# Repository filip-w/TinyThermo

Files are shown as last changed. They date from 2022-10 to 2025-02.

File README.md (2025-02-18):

# TinyThermo
Low-cost and accurate open source thermocouple to CAN module for the DIY enthusiast.

Modular design, with readily available modules.
Based on Arduino Nano, MAX31855 and MCP2515 CAN-module.

Librarys used
- FIR filter by Leeman Geophysical LLC
- autowp-mcp2515 by autowp
- Adafruit MAX31855 library by Adafruit

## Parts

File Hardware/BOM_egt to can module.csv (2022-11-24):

ID | Name | Designator | Footprint | Quantity | Manufacturer Part | Farnell Part | Manufacturer | Supplier | Supplier Part | Price [sek] | Sum price [sek]
1 | 2.2u 35v | C1 | CASE-A_3216 | 1 |  | 2524560 |  |  |  | 0,928 | 0,928
2 | 0.33u 35v | C2 | CASE-A_3216 | 1 |  | 1457422 |  |  |  |  | 0
3 | 47u 10v | C3 | CASE-A_3216 | 1 |  | 2491477 |  |  |  |  | 0
4 | 2.2u 16v | C4 | CASE-A_3216 | 1 |  | 197233 |  |  |  |  | 0
5 | 0.1u 10v | C5,C6,C9,C11,C13 | C0603 | 5 |  | 3880987 |  |  |  |  | 0
6 | 10n 10v | C7,C8,C10,C12 | C0603 | 4 |  | 2470449 |  |  |  |  | 0
7 | HDR-F-2.54_1x2 | H1 | HDR-F-2.54_1X2 | 2 |  | 1593458 |  | LCSC | C49661 | 00.38 | 01.16
8 | PCC-SMD-20 | J1,J2,J3,J4 | OMEGA_PCC-SMD-20 | 8 |  | 3409359 |  |  |  | 17.14 | 17.52
9 | ARDUINO-NANO-3.0#ISP | M1 | ARDUINO-NANO-3.0#ISP | 1 |  |  |  |  |  | 87 | 87
10 | M12 Panel to PCB Connector 5pin | U1 | M12 PANEL TO PCB CONNECTOR 5PIN | 1 | T4145015051-001 |  | TE Connectivity |  | T4145015051-001 | 89 | 89
11 | Mini DC - DC buck converter setoutput | U2 | MINI-DC-DC-BUCK | 1 |  |  |  |  |  | 9 | 9
12 | MCP2515-CAN-BUS-MODULE | U3 | MCP2515-CAN-MODULE | 1 |  |  |  |  |  | 75 | 75
13 | 4-POS-DIP | U3 | 4-POS-DIP-SMD | 1 |  | IKN0403000 |  |  |  | 12 | 12
14 | logic shifter | U5,U6 | LOGIC SHIFTER | 2 |  |  |  |  |  | 22 | 44
15 | MAX31855KASA+T | U7,U8,U9,U10 | SO-8_L4.9-W3.9-P1.27-LS5.9-BL | 4 | MAX31855KASA+T | 2515622 | MAXIM | LCSC | C52028 | 83,37 | 333,48
16 | 15pin header (Arduino nano) |  |  | 2 |  | 3225931 |  |  |  |  | 0
17 | 1455l801BK box |  |  | 1 |  | 2988624 |  |  |  | 277 | 277
18 | 621 bracket |  |  | 2 |  | 2909361 |  |  |  | 04.42 | 09.24
19 | 6pin header levelshifter |  |  | 4 |  | 1593462 |  |  |  |  | 0
20 | 4 pin header powersupply |  |  | 1 |  | 1593460 |  |  |  |  | 0
21 | 7 pin header Can module |  |  | 1 |  | 2984569 |  |  |  |  | 0

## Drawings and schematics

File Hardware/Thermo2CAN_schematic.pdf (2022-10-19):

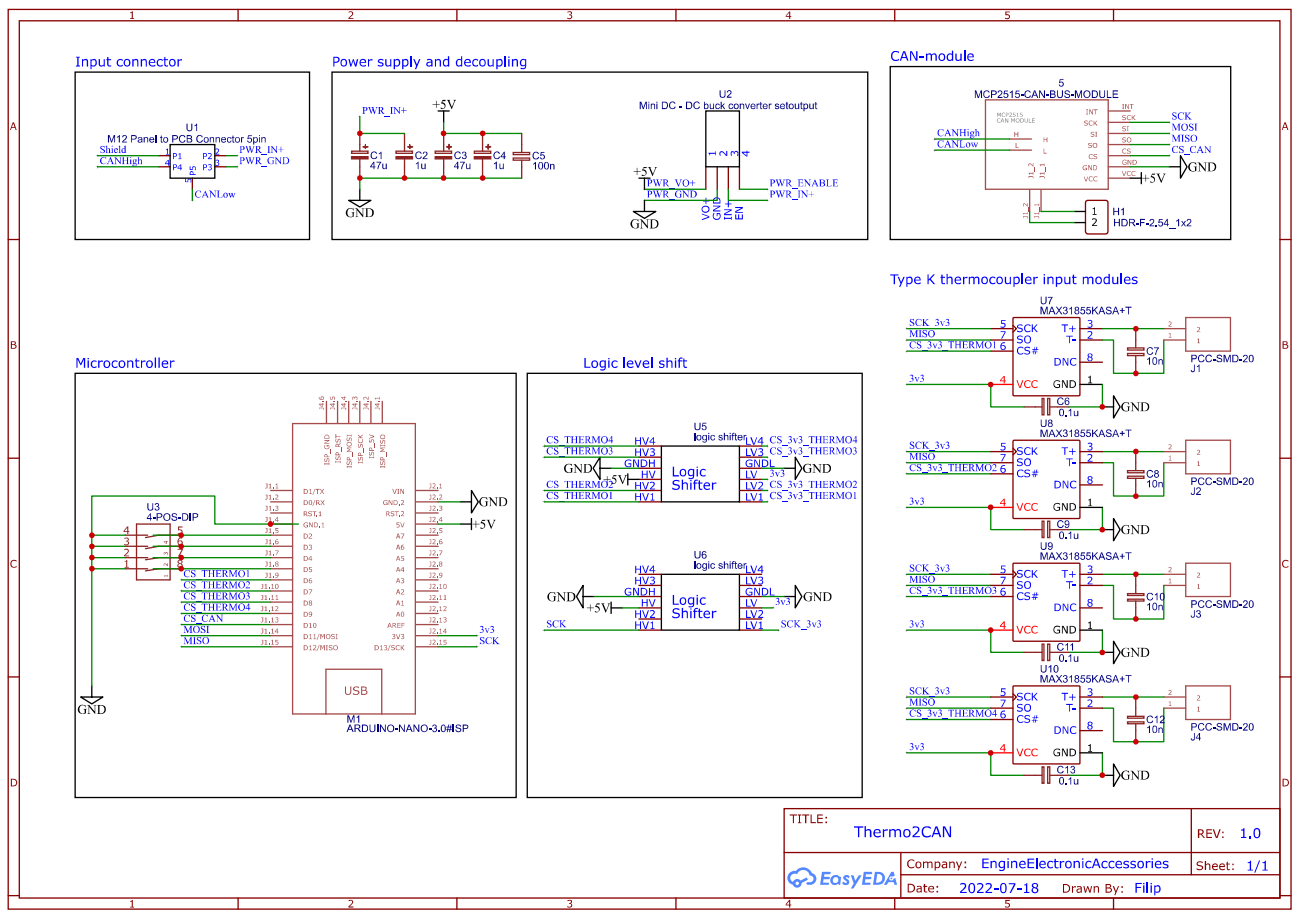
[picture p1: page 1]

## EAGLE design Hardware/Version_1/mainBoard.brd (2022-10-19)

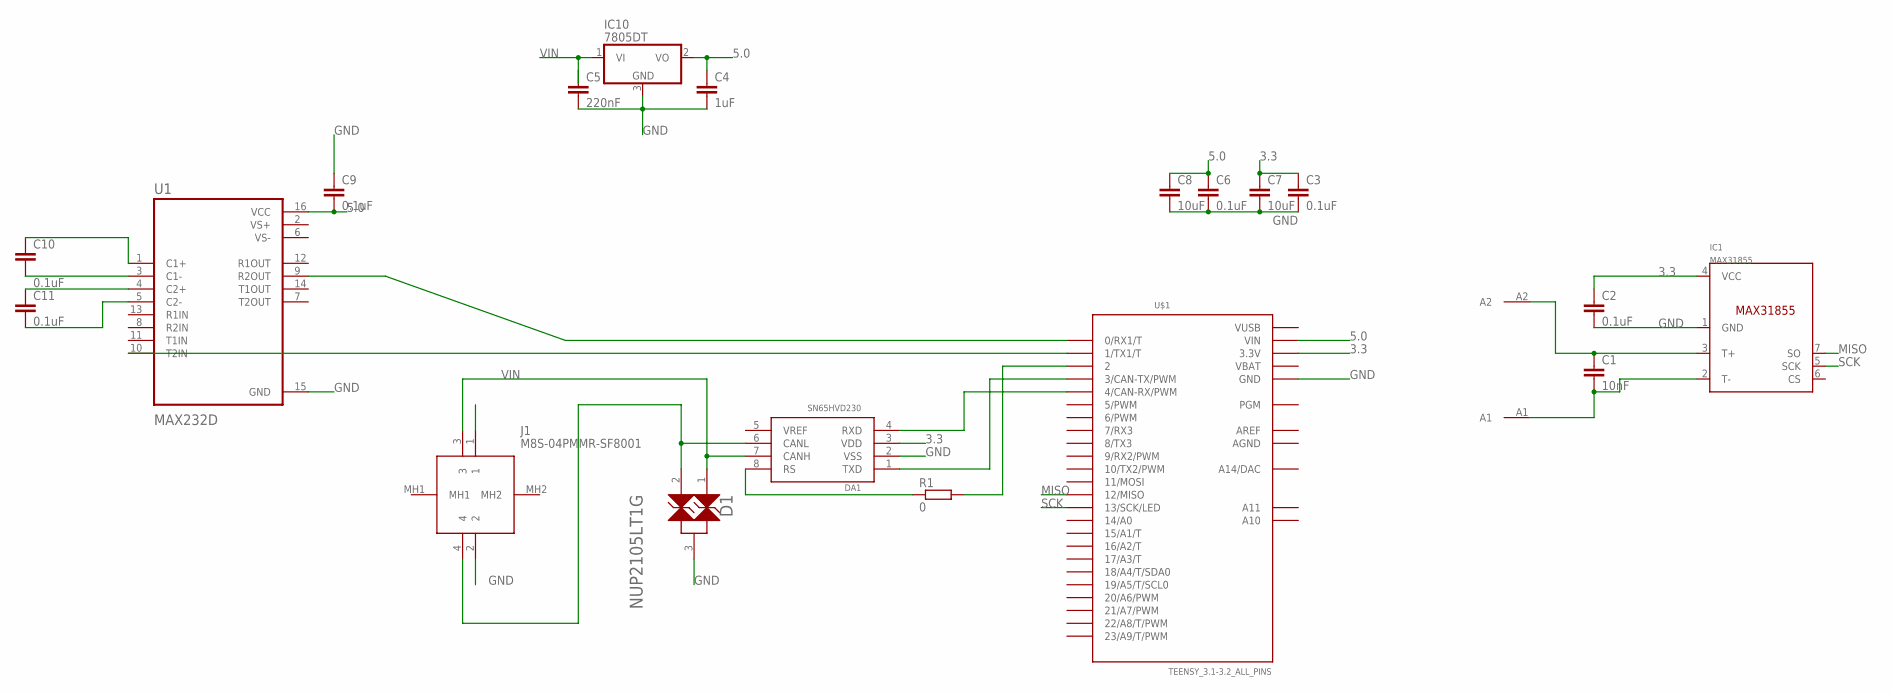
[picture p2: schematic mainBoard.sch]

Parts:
C1: 10nF; C0805
C2, C3, C6, C9, C10, C11: 0.1uF; C0805
C4: 1uF; C0805
C5: 220nF; C0805
C7, C8: 10uF; C0805
D1: ON_SEMICONDUCTOR_NUP2105LT1GON_SEMICONDUCTOR_NUP2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; ON_SEMICONDUCTOR_NUP2105LT1G_0
DA1: SN65HVD230; SO08
IC1: MAX31855; SOIC8
IC10: 7805DT; TO252
J1: M8S-04PMMR-SF8001; M8S04PMMRSF8001
R1: 0; R0805
U1: MAX232D; SOIC127P600X175-16N
U$1: TEENSY_3.1-3.2_ALL_PINS; TEENSY_3.0-3.2&LC_ALL_PINS
U$2: PCC-SMD

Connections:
3.3: C2.1, C3.1, C7.1, DA1.3 (VDD), IC1.4 (VCC), U$1.3.3V, U$1.3.3V1 (3.3V)
5.0: C4.1, C6.1, C8.1, C9.2, IC10.2 (VO), U1.16 (VCC), U$1.VIN
AGND: U$1.AGND
AREF: U$1.AREF
GND: C2.2, C3.2, C4.2, C5.2, C6.2, C7.2, C8.2, C9.1, D1.3 (3_K), DA1.2 (VSS), IC1.1 (GND), IC10.3 (GND), J1.2, U1.15 (GND), U$1.GND, U$1.GND1 (GND)
MISO: IC1.7 (SO), U$1.12 (12/MISO)
unnamed: C1.1, IC1.3 (T+), U$2.A2
unnamed: C1.2, IC1.2 (T-), U$2.A1
unnamed: DA1.1 (TXD), U$1.3 (3/CAN-TX/PWM)
unnamed: DA1.4 (RXD), U$1.4 (4/CAN-RX/PWM)
unnamed: R1.2, U$1.2
unnamed: DA1.8 (RS), R1.1
unnamed: C10.1, U1.1 (C1+)
unnamed: C10.2, U1.3 (C1-)
unnamed: C11.2, U1.5 (C2-)
unnamed: C11.1, U1.4 (C2+)
unnamed: U1.10 (T2IN), U$1.1 (1/TX1/T)
unnamed: U1.9 (R2OUT), U$1.0 (0/RX1/T)
unnamed: D1.1 (1_K), DA1.7 (CANH), J1.3
unnamed: D1.2 (2_K), DA1.6 (CANL), J1.4
SCK: IC1.5 (SCK), U$1.13 (13/SCK/LED)
VBAT: U$1.VBAT
VIN: C5.1, IC10.1 (VI), J1.1
VS+: U1.2 (VS+)
VS-: U1.6 (VS-)
VUSB: U$1.VUSB

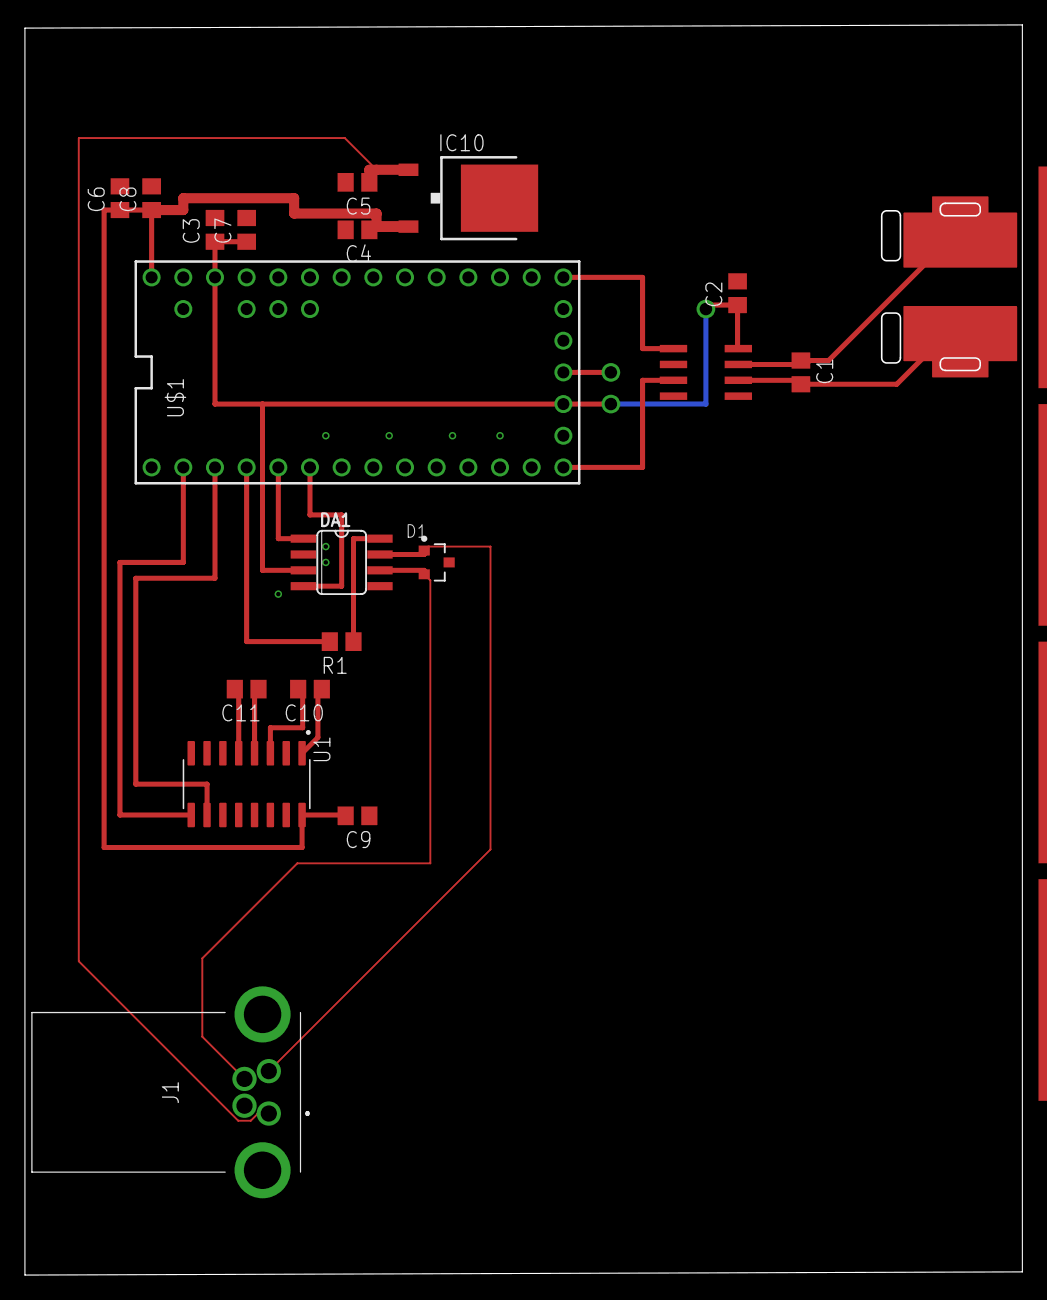
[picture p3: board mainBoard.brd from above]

Board: 2 copper layers, 80.0 x 100.3 mm, 20 parts (0 on the bottom side), 20 nets.

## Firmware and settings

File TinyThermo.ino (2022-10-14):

#include <SPI.h>
#include "Adafruit_MAX31855.h"
#include <mcp2515.h>
#include <FIR.h>

//General setup
#define BaseCanID 0x600
#define UpdateRate 10 //Frontend thermocouple scan rate and CAN-message update rate in Hz.
#define serialDebug false

struct thermocoupleChannel{
   int channelNumber;
   Adafruit_MAX31855 thermocoupleFrontend;
   FIR<double, 10> fir_avg;
};

struct can_frame canMsg1;
enum CAN_SPEED BaudRate;
// For a moving average we use all ones as coefficients.
double coef_avg[10] = {1., 1., 1., 1., 1., 1., 1., 1., 1., 1.};
byte Lowpass;


//Chip select pins
#define MAXCS1          6
#define MAXCS2          7
#define MAXCS3          8
#define MAXCS4          9
#define CANMODCS        10

//Input settings swithes
#define SW_CANID1       5
#define SW_CANID2       4
#define SW_CANBaudRate  3 
#define SW_Lowpass      2

MCP2515 mcp2515(CANMODCS);

thermocoupleChannel thermocoupleChannels[4]{
  {1, MAXCS1},
  {2, MAXCS2},
  {3, MAXCS3},
  {4, MAXCS4},
};

void setup() {

  Serial.begin(9600);

  while (!Serial) delay(1); // wait for Serial on Leonardo/Zero, etc

  Serial.println("Initializing sensors...");
  
  delay(500); // wait for MAX chip to stabilize

  for(byte i = 0; i < sizeof(thermocoupleChannels)/sizeof(thermocoupleChannel); i++){
    if (!thermocoupleChannels[i].thermocoupleFrontend.begin()) {
      Serial.println("ERROR. Sensor " + i);
      while (1) delay(10);
    }

    // Set the coefficients of the filter
    thermocoupleChannels[i].fir_avg.setFilterCoeffs(coef_avg);
  }
  Serial.println("DONE.");

  //Read setting switches
  //Remember that state switch reading is inverted in relation to physical position
  Serial.println("Reading settings switches...");
  pinMode(SW_CANID1, INPUT_PULLUP);
  pinMode(SW_CANID2, INPUT_PULLUP);
  pinMode(SW_CANBaudRate, INPUT_PULLUP);
  pinMode(SW_Lowpass, INPUT_PULLUP);

  byte canid_LSB = !digitalRead(SW_CANID1);
  Serial.print("canid_LSB: ");
  Serial.println(canid_LSB);
  byte canid_MSB = !digitalRead(SW_CANID2);
  Serial.print("canid_MSB: ");
  Serial.println(canid_MSB);
  int canid = canid_MSB << 1 | canid_LSB | BaseCanID;
  Serial.print("CANid: ");
  Serial.println(canid);

  //Read CAN baudrate switch and set baudrate accordingly
  //Switch state 0 = 250Kbs/s
  //Switch state 1 = 500Kbs/s
  Serial.print("SW_CANBaudRate: ");
  if (digitalRead(SW_CANBaudRate)) {
    BaudRate = CAN_250KBPS;
    Serial.println("250KBPS");
  }
  else {
    BaudRate = CAN_500KBPS;
    Serial.println("500KBPS");
  }
  
  Lowpass = !digitalRead(SW_Lowpass);
  Serial.print("SW_Lowpass: ");
  Serial.println(Lowpass);

  Serial.println("DONE.");

  canMsg1.can_id  = canid;
  canMsg1.can_dlc = 8;
  canMsg1.data[0] = 0x00;
  canMsg1.data[1] = 0x00;
  canMsg1.data[2] = 0x00;
  canMsg1.data[3] = 0x00;
  canMsg1.data[4] = 0x00;
  canMsg1.data[5] = 0x00;
  canMsg1.data[6] = 0x00;
  canMsg1.data[7] = 0x00;

  Serial.println("Initializing CAN module...");
  mcp2515.reset();
  mcp2515.setBitrate(BaudRate,MCP_8MHZ);
  mcp2515.setNormalMode();
  Serial.println("DONE.");
}

void loop() {
  int canMsgIndex=0;
  double c;
  for(byte i = 0; i < sizeof(thermocoupleChannels)/sizeof(thermocoupleChannels[0]); i++){
    if (serialDebug) {
      Serial.print("Internal Temp ");
      Serial.print(i+1);
      Serial.print(":");
      Serial.print(thermocoupleChannels[i].thermocoupleFrontend.readInternal());
      Serial.print(",");
    }

    if (!Lowpass) {
      c = thermocoupleChannels[i].thermocoupleFrontend.readCelsius();
    }
    else{
      c = thermocoupleChannels[i].fir_avg.processReading(thermocoupleChannels[i].thermocoupleFrontend.readCelsius());
    }
      
    if (isnan(c)) {
      if (serialDebug) Serial.print("Fault(s) detected!");
      uint8_t e = thermocoupleChannels[i].thermocoupleFrontend.readError();
      if (e & MAX31855_FAULT_OPEN){
        c=0xFFFF;
        if (serialDebug) Serial.print("Open - no connections.");
        canMsg1.data[canMsgIndex++] = int(c*10);
        canMsg1.data[canMsgIndex++] = int(c*10) >> 8;
      } 
      if (e & MAX31855_FAULT_SHORT_GND){
        c=0xFFFE;
        if (serialDebug) Serial.print("Short-circuited to GND.");
        canMsg1.data[canMsgIndex++] = int(c*10);
        canMsg1.data[canMsgIndex++] = int(c*10) >> 8;
      } 
      if (e & MAX31855_FAULT_SHORT_VCC){
        c=0xFFFD;
        if (serialDebug) Serial.print("Short-circuited to VCC.");
        canMsg1.data[canMsgIndex++] = int(c*10);
        canMsg1.data[canMsgIndex++] = int(c*10) >> 8;
      }
      if (serialDebug) Serial.print(",");
    } else {
      if (serialDebug) {
        Serial.print("Temp");
        Serial.print(i+1);
        Serial.print(":");
        Serial.print(int(c*10));
        Serial.print(",");
      }
      int test = 0xFF;
      test = test | int(c*10);
      canMsg1.data[canMsgIndex++] = int(c*10);
      canMsg1.data[canMsgIndex++] = int(c*10) >> 8;
    }
    //Serial.print("F = ");
    //Serial.println(thermocouple.readFahrenheit());
  }
  if (serialDebug) Serial.println();

  mcp2515.sendMessage(&canMsg1);
  //mcp2515.sendMessage(&canMsg2);
  delay(float(1)/UpdateRate*1000); //Crude wait, should use a dynamic time offset depending.
}

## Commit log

2022-02-01 Added Hardware folder and Eagle project files
    [mainBoard.brd, mainBoard.sch]
2022-09-26 Added main program
    Support for 4 channel temperature reading
2022-09-27 Adding support reading settings switches.
2022-10-05 Added support for CAN module. Send 2 fixed CAN-frames.
2022-10-06 Send temperature over CAN in one message
2022-10-10 Trying out FIR filter library. Creating struct for thermocouple channels.
2022-10-13 Adding support for CAN baudrate switch setting.
2022-10-14 Adding support for 1 sec avg FIR filter
2022-10-19 Adding schematic
    [mainBoard.brd, mainBoard.sch]
2022-10-28 Adding BOM-list
    [BOM_egt to can module.csv]
2022-11-24 Wrong box, changing article number in BOM
    [BOM_egt to can module.csv]
2025-12-13 Update README with hardware and Tindie store info
    Added hardware connectors section and Tindie store link.
